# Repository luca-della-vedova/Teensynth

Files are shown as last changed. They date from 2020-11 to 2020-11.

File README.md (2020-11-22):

# Teensynth

The aim of the project is to create a companion board for MIDI compatible keyboards / electric pianos and augment them with commonly used / needed features such as:

* Midi recording: Sample and forward USB Midi signal and forward it to the host machine (or record in an SD card).
* Audio recording: Record Line out / Headphone out (for now only the latter is implemented) and stream it to the host through an Audio USB device interface.
* Midi synthesizer: Read MIDI files from SD card or receive MIDI commands from USB interface and synthesize them, as well as mix them with the audio signal (i.e. create a midi base and jam on it!)
* Implement pitch bend: For keyboards that support pitch bend MIDI commands but don't have a pitch wheel, create one with a joystick / potentiometer.

The board aims to be used in two ways:

### Standalone mode

All the recording outputs are to SD card, all the inputs (i.e. MIDI) are from SD card or firmware, control is done through hardware buttons and feedback to the user is through the Grove compatible I2C LCD display. 

### USB device mode

The device implements bidirectional MIDI (send the keyboard output to the host machine / synthesize the host machine's output) and Audio streaming to the host machine.
Streaming audio from the host machine to the onboard DAC should also be possible but is not a priority right now.

# Hardware

The hardware has been designed with kicad, it is a carrier board for  Teensy 4.1 and the Adafruit VS1053B breakout board.

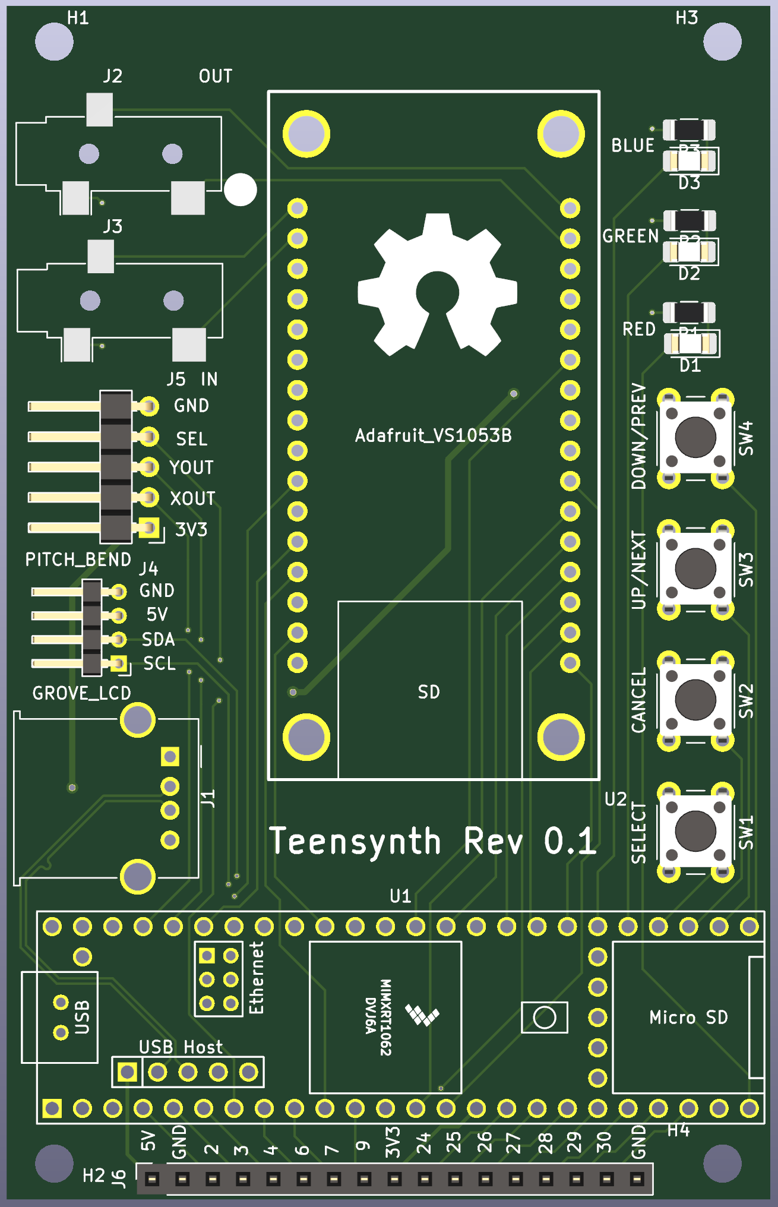
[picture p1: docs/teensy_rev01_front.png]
teensy_rev01_front


# Firmware

The firmware has been developed with the Arduino / Teensyduino IDE, using external libraries (such as Adafruit VS1053B library) when necessary.

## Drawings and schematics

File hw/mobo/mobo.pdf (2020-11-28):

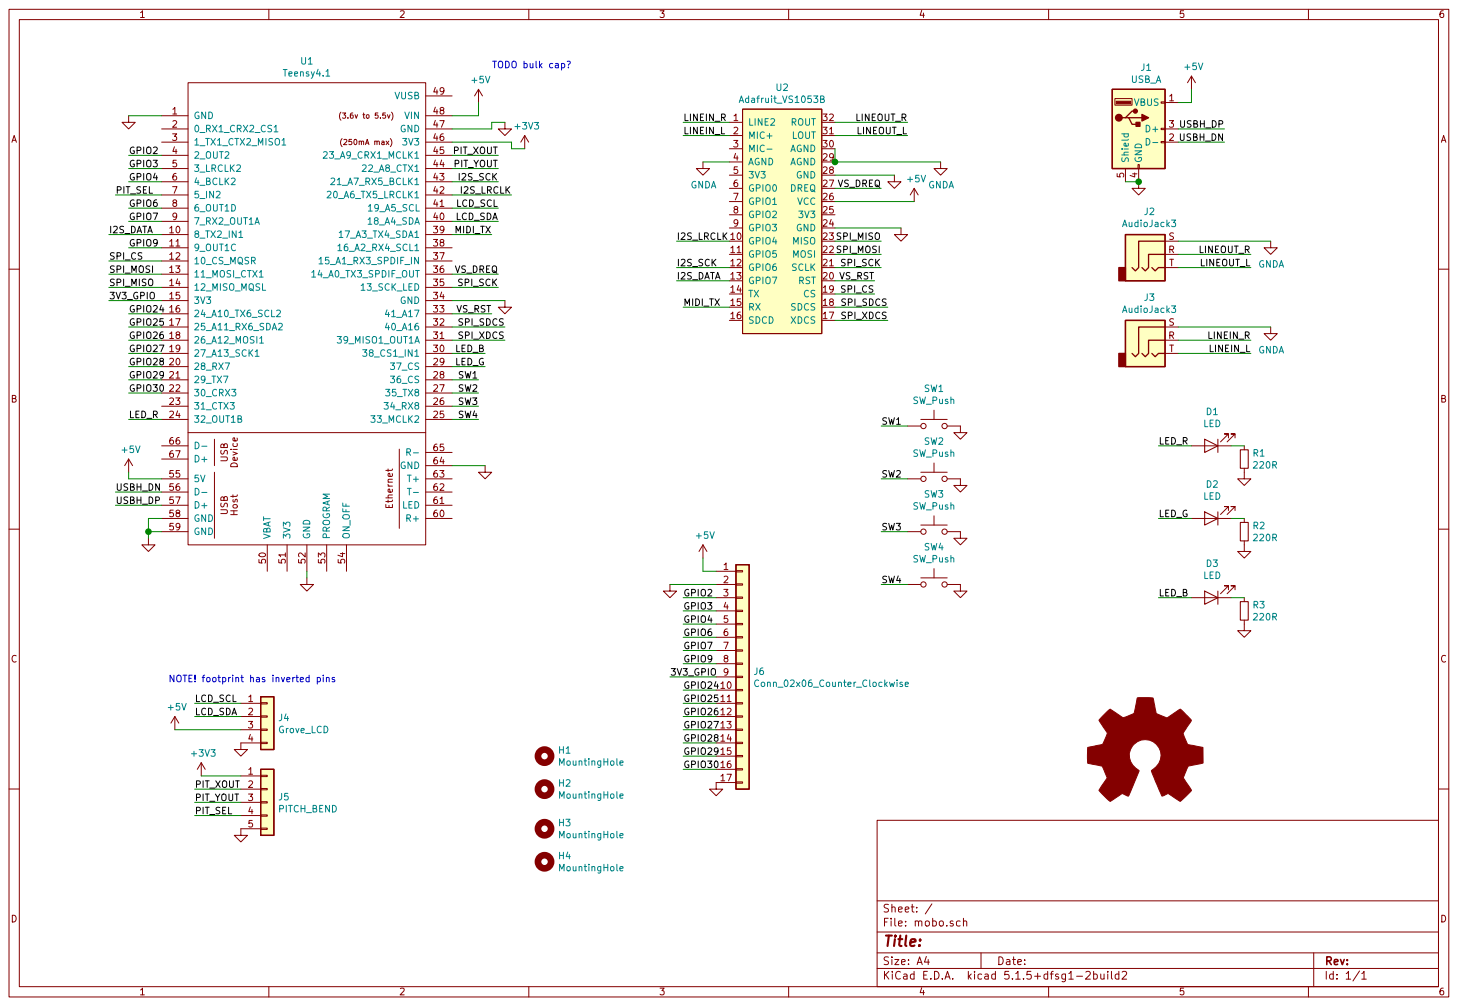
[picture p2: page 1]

NOTE! footprint has inverted pins
LCD_SDA

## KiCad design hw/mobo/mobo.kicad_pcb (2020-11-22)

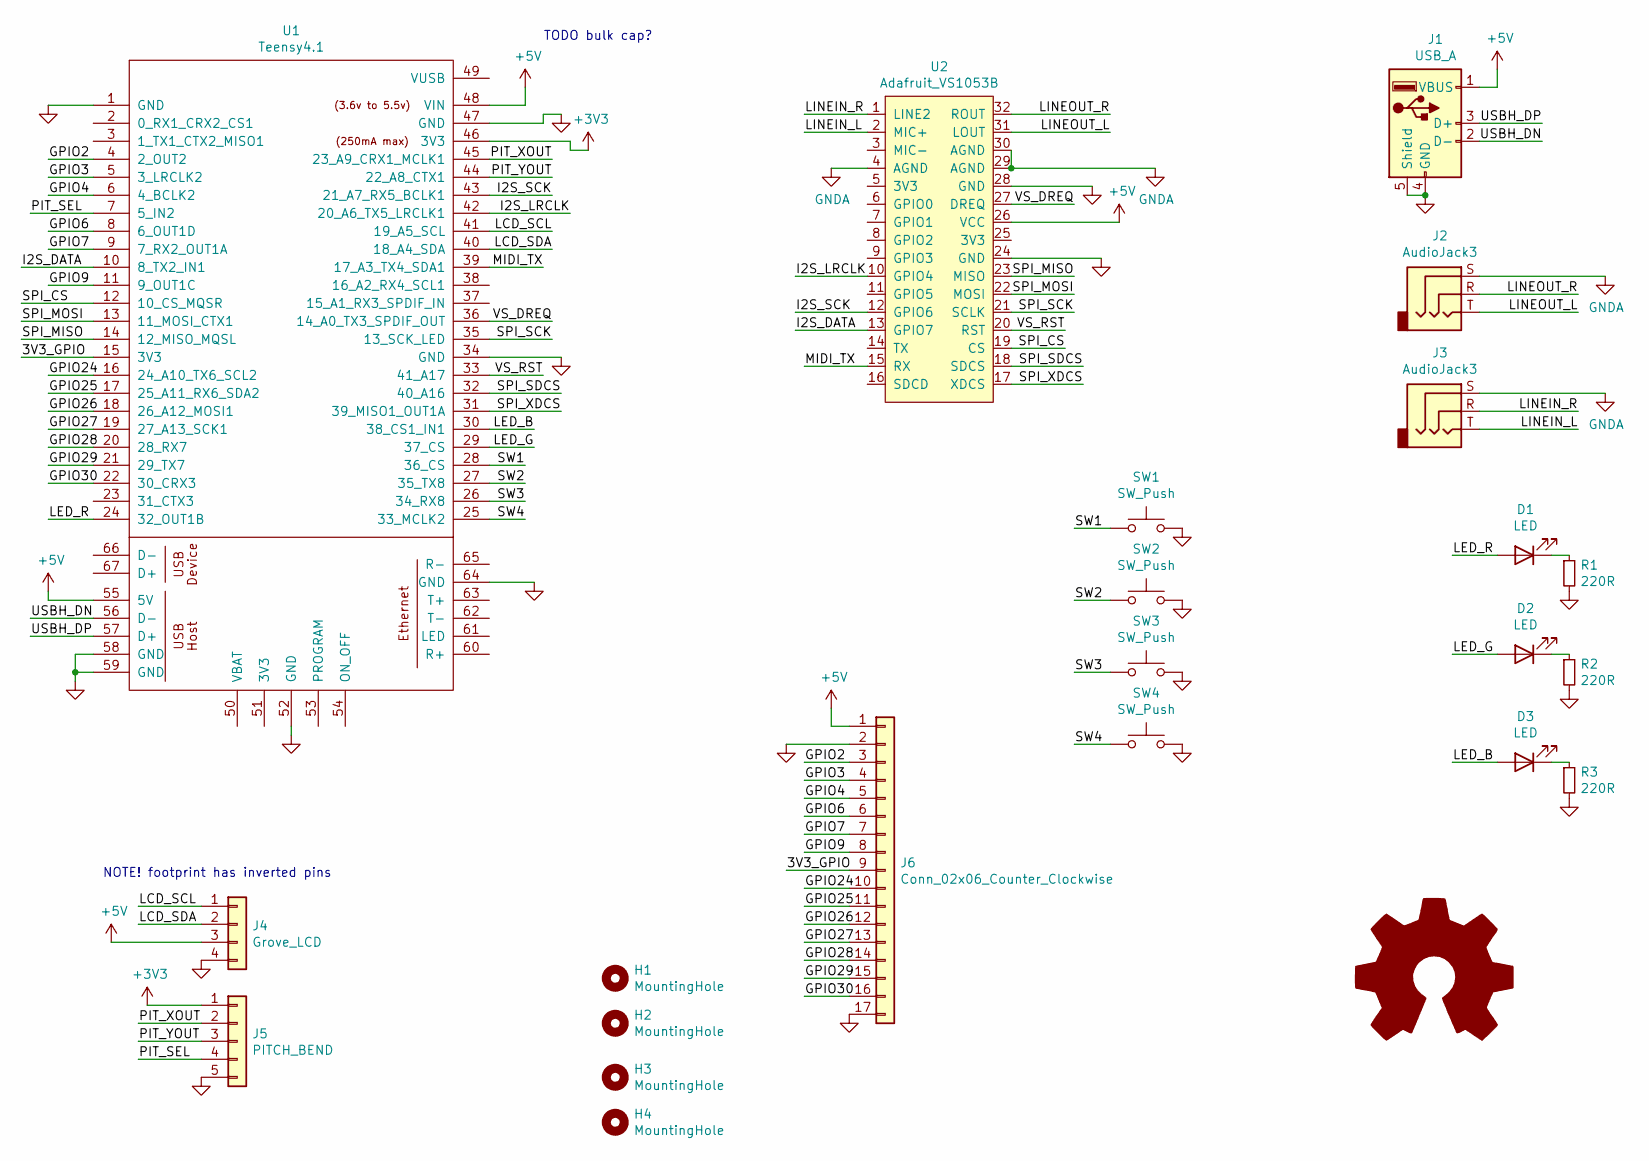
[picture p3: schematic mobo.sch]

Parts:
D1, D2, D3: LED; LED_1206_3216Metric_Pad1.42x1.75mm_HandSolder
H1, H2, H3, H4: MountingHole; MountingHole_3.2mm_M3
J1: USB_A; USB_A_Molex_67643_Horizontal
J2, J3: AudioJack3; Jack_3.5mm_CUI_SJ-3523-SMT_Horizontal
J4: Grove_LCD; PinHeader_1x04_P2.00mm_Horizontal
J5: PITCH_BEND; PinHeader_1x05_P2.54mm_Horizontal
J6: Conn_02x06_Counter_Clockwise; PinSocket_1x17_P2.54mm_Vertical
LOGO1: Logo_Open_Hardware_Large; OSHW-Symbol_13.4x12mm_SilkScreen
R1, R2, R3: 220R; R_1206_3216Metric_Pad1.30x1.75mm_HandSolder
SW1, SW2, SW3, SW4: SW_Push; SW_PUSH_6mm_H5mm
U1: Teensy4.1; Teensy41
U2: Adafruit_VS1053B

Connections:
+3V3: J5.1, U1.46 (3V3)
+5V: J1.1 (VBUS), J4.3, J6.1, U1.48 (VIN), U1.55 (5V), U2.26 (VCC)
/3V3_GPIO: J6.9, U1.15 (3V3)
/GPIO2: J6.3, U1.4 (2_OUT2)
/GPIO3: J6.4, U1.5 (3_LRCLK2)
/GPIO4: J6.5, U1.6 (4_BCLK2)
/GPIO6: J6.6, U1.8 (6_OUT1D)
/GPIO7: J6.7, U1.9 (7_RX2_OUT1A)
/GPIO9: J6.8, U1.11 (9_OUT1C)
/GPIO24: J6.10, U1.16 (24_A10_TX6_SCL2)
/GPIO25: J6.11, U1.17 (25_A11_RX6_SDA2)
/GPIO26: J6.12, U1.18 (26_A12_MOSI1)
/GPIO27: J6.13, U1.19 (27_A13_SCK1)
/GPIO28: J6.14, U1.20 (28_RX7)
/GPIO29: J6.15, U1.21 (29_TX7)
/GPIO30: J6.16, U1.22 (30_CRX3)
/I2S_DATA: U1.10 (8_TX2_IN1), U2.13 (GPIO7)
/I2S_LRCLK: U1.42 (20_A6_TX5_LRCLK1), U2.10 (GPIO4)
/I2S_SCK: U1.43 (21_A7_RX5_BCLK1), U2.12 (GPIO6)
/LCD_SCL: J4.1, U1.41 (19_A5_SCL)
/LCD_SDA: J4.2, U1.40 (18_A4_SDA)
/LED_B: D3.2 (A), U1.30 (38_CS1_IN1)
/LED_G: D2.2 (A), U1.29 (37_CS)
/LED_R: D1.2 (A), U1.24 (32_OUT1B)
/LINEIN_L: J3.T, U2.2 (MIC+)
/LINEIN_R: J3.R, U2.1 (LINE2)
/LINEOUT_L: J2.T, U2.31 (LOUT)
/LINEOUT_R: J2.R, U2.32 (ROUT)
/MIDI_TX: U1.39 (17_A3_TX4_SDA1), U2.15 (RX)
/PIT_SEL: J5.4, U1.7 (5_IN2)
/PIT_XOUT: J5.2, U1.45 (23_A9_CRX1_MCLK1)
/PIT_YOUT: J5.3, U1.44 (22_A8_CTX1)
/SPI_CS: U1.12 (10_CS_MQSR), U2.19 (CS)
/SPI_MISO: U1.14 (12_MISO_MQSL), U2.23 (MISO)
/SPI_MOSI: U1.13 (11_MOSI_CTX1), U2.22 (MOSI)
/SPI_SCK: U1.35 (13_SCK_LED), U2.21 (SCLK)
/SPI_SDCS: U1.32 (40_A16), U2.18 (SDCS)
/SPI_XDCS: U1.31 (39_MISO1_OUT1A), U2.17 (XDCS)
/SW1: SW1.1, U1.28 (36_CS)
/SW2: SW2.1, U1.27 (35_TX8)
/SW3: SW3.1, U1.26 (34_RX8)
/SW4: SW4.1, U1.25 (33_MCLK2)
/USBH_DN: J1.2 (D-), U1.56 (D-)
/USBH_DP: J1.3 (D+), U1.57 (D+)
/VS_DREQ: U1.36 (14_A0_TX3_SPDIF_OUT), U2.27 (DREQ)
/VS_RST: U1.33 (41_A17), U2.20 (RST)
GND: J1.4 (GND), J1.5 (Shield), J4.4, J5.5, J6.2, J6.17, R1.2, R2.2, R3.2, SW1.2, SW2.2, SW3.2, SW4.2, U1.1 (GND), U1.34 (GND), U1.47 (GND), U1.52 (GND), U1.58 (GND), U1.59 (GND), U1.64 (GND), U2.24 (GND), U2.28 (GND)
GNDA: J2.S, J3.S, U2.4 (AGND), U2.29 (AGND), U2.30 (AGND)
unnamed: D1.1 (K), R1.1
unnamed: D2.1 (K), R2.1
unnamed: D3.1 (K), R3.1

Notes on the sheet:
TODO bulk cap?
NOTE! footprint has inverted pins

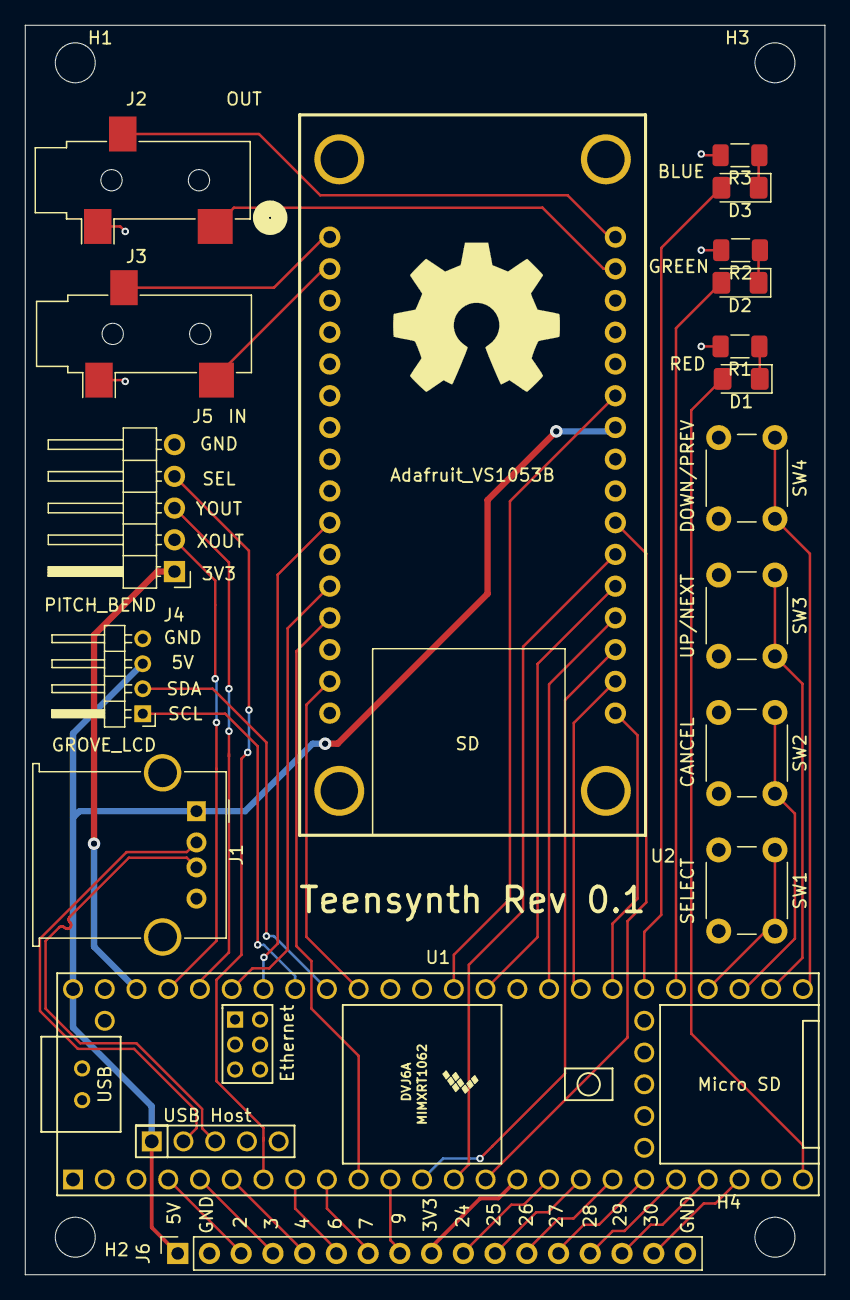
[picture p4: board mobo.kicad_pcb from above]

Board: 2 copper layers, 64.0 x 100.0 mm, 23 parts (0 on the bottom side), 51 nets.

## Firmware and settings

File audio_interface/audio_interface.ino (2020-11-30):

#define PREFER_SDFAT_LIBRARY
#define FILES_PER_PAGE 10
#include <array>

#include <SdFat.h>

#include <USBHost_t36.h>
#include <Metro.h>
#include <Adafruit_VS1053.h>
#include "hw_defs.h"
#include "vs1053_plugins.h"
#include "lcd_driver.h"

#include <MD_MIDIHelper.h>
#include <MD_MIDIFile.h>

USBHost myusb;
USBHub hub1(myusb);
USBHub hub2(myusb);
MIDIDevice midi1(myusb);

Adafruit_VS1053 vs_codec =
  Adafruit_VS1053(VS1053_RESET, VS1053_CS, VS1053_DCS, VS1053_DREQ);


#define VS1053_BANK_MELODY 0x79
#define VS1053_GM1_OCARINA 80

#define MIDI_NOTE_ON  0x90
#define MIDI_NOTE_OFF 0x80
#define MIDI_CHAN_MSG 0xB0
#define MIDI_CHAN_BANK 0x00
#define MIDI_CHAN_VOLUME 0x07
#define MIDI_CHAN_PROGRAM 0xC0

void midiSetInstrument(uint8_t chan, uint8_t inst) {
  if (chan > 15) return;
  inst --; // page 32 has instruments starting with 1 not 0 :(
  if (inst > 127) return;
  
  VS1053_MIDI.write(MIDI_CHAN_PROGRAM | chan);  
  VS1053_MIDI.write(inst);
}

void midiSetChannelVolume(uint8_t chan, uint8_t vol) {
  if (chan > 15) return;
  if (vol > 127) return;
  
  VS1053_MIDI.write(MIDI_CHAN_MSG | chan);
  VS1053_MIDI.write(MIDI_CHAN_VOLUME);
  VS1053_MIDI.write(vol);
}

void midiSetChannelBank(uint8_t chan, uint8_t bank) {
  if (chan > 15) return;
  if (bank > 127) return;
  
  VS1053_MIDI.write(MIDI_CHAN_MSG | chan);
  VS1053_MIDI.write((uint8_t)MIDI_CHAN_BANK);
  VS1053_MIDI.write(bank);
}

SdFat  SD;
MD_MIDIFile SMF;

// The files in the tune list should be located on the SD card 
// or an error will occur opening the file and the next in the 
// list will be opened (skips errors).
const char *tuneList[] = 
{
  "sandstorm.mid",  // simplest and shortest file
  "pirates.mid",
};
const uint16_t WAIT_DELAY = 2000; // ms

void midiCallback(midi_event *pev)
// Called by the MIDIFile library when a file event needs to be processed
// thru the midi communications interface.
// This callback is set up in the setup() function.
{
  if ((pev->data[0] >= 0x80) && (pev->data[0] <= 0xe0))
  {
    VS1053_MIDI.write(pev->data[0] | pev->channel);
    VS1053_MIDI.write(&pev->data[1], pev->size-1);
  }
  else
    VS1053_MIDI.write(pev->data, pev->size);
}

void midiSilence(void)
// Turn everything off on every channel.
// Some midi files are badly behaved and leave notes hanging, so between songs turn
// off all the notes and sound
{
  midi_event ev;

  // All sound off
  // When All Sound Off is received all oscillators will turn off, and their volume
  // envelopes are set to zero as soon as possible.
  ev.size = 0;
  ev.data[ev.size++] = 0xb0;
  ev.data[ev.size++] = 120;
  ev.data[ev.size++] = 0;

  for (ev.channel = 0; ev.channel < 16; ev.channel++)
    midiCallback(&ev);
}

void midifile_setup(void)
{
  // Set up LED pins
  pinMode(READY_LED, OUTPUT);
  pinMode(SD_ERROR_LED, OUTPUT);
  pinMode(SMF_ERROR_LED, OUTPUT);
  pinMode(BEAT_LED, OUTPUT);

  // reset LEDs
  digitalWrite(READY_LED, LOW);
  digitalWrite(SD_ERROR_LED, LOW);
  digitalWrite(SMF_ERROR_LED, LOW);
  digitalWrite(BEAT_LED, LOW);

  SdioConfig sd_config;
  // Initialize SD
  if (!SD.begin(sd_config))
  {
    digitalWrite(SD_ERROR_LED, HIGH);
    while (true)
      Serial.println("SD init failed");
  }

  // Initialize MIDIFile
  SMF.begin(&SD);
  SMF.setMidiHandler(midiCallback);
  
  digitalWrite(READY_LED, HIGH);
}

void tickMetronome(void)
// flash a LED to the beat
{
  static uint32_t lastBeatTime = 0;
  static boolean  inBeat = false;
  uint16_t  beatTime;

  beatTime = 60000/SMF.getTempo();    // msec/beat = ((60sec/min)*(1000 ms/sec))/(beats/min)
  if (!inBeat)
  {
    if ((millis() - lastBeatTime) >= beatTime)
    {
      lastBeatTime = millis();
      digitalWrite(BEAT_LED, HIGH);
      inBeat = true;
    }
  }
  else
  {
    if ((millis() - lastBeatTime) >= 100) // keep the flash on for 100ms only
    {
      digitalWrite(BEAT_LED, LOW);
      inBeat = false;
    }
  }
}

void midifile_loop(void)
{
  static enum { S_IDLE, S_PLAYING, S_END, S_WAIT_BETWEEN } state = S_IDLE;
  static uint16_t currTune = ARRAY_SIZE(tuneList);
  static uint32_t timeStart;

  switch (state)
  {
  case S_IDLE:    // now idle, set up the next tune
    {
      int err;

      digitalWrite(READY_LED, LOW);
      digitalWrite(SMF_ERROR_LED, LOW);

      currTune++;
      if (currTune >= ARRAY_SIZE(tuneList))
        currTune = 0;

      // use the next file name and play it
      err = SMF.load(tuneList[currTune]);
      if (err != MD_MIDIFile::E_OK)
      {
        digitalWrite(SMF_ERROR_LED, HIGH);
        timeStart = millis();
        state = S_WAIT_BETWEEN;
      }
      else
      {
        state = S_PLAYING;
      }
    }
    break;

  case S_PLAYING: // play the file
    if (!SMF.isEOF())
    {
      if (SMF.getNextEvent())
        tickMetronome();
    }
    else
      state = S_END;
    break;

  case S_END:   // done with this one
    SMF.close();
    midiSilence();
    timeStart = millis();
    state = S_WAIT_BETWEEN;
    break;

  case S_WAIT_BETWEEN:    // signal finished with a dignified pause
    digitalWrite(READY_LED, HIGH);
    if (millis() - timeStart >= WAIT_DELAY)
      state = S_IDLE;
    break;

  default:
    state = S_IDLE;
    break;
  }
}

void VS1053_init()
{
  delay(100);
  if (! vs_codec.begin()) { // initialise the music player
      Serial.println(F("Couldn't find VS1053, do you have the right pins defined?"));
  }
  Serial.println("VS1053 found");
  // Magic stuff to enable I2S based on datasheet
  vs_codec.sciWrite(0x7, 0xC017);
  vs_codec.sciWrite(0x6, 0x00F0);

  // Enable I2S, start with WRAMADDR
  vs_codec.sciWrite(0x7, 0xC040);
  // Then WRAM
  vs_codec.sciWrite(0x6, 0x000E); // PUT E FOR 192KHZ
  vs_codec.applyPatch(patches_plugin, PATCHES_PLUGIN_SIZE);// Add here
  // Start the patches
  while(digitalRead(VS1053_DREQ) == 0);
  vs_codec.applyPatch(midistart_plugin, MIDISTART_PLUGIN_SIZE);// Add here
//  // Start midi plugin
//  vs_codec.sciWrite(0xA, 0x50);
  delay(50);
  
  vs_codec.applyPatch(admix_plugin, ADMIX_PLUGIN_SIZE);// Add here

  // Start the ADMIX plugin
  // Lower gain
  vs_codec.sciWrite(0xC, 0xFFFD);
  vs_codec.sciWrite(0xA, 0x0F00);
  while(digitalRead(VS1053_DREQ) == 0)
  {
    Serial.println("Waiting for ADMIX start");
  }
  delay(100);
  
  VS1053_MIDI.begin(31250); // MIDI uses a 'strange baud rate'
  midiSetChannelBank(0, VS1053_BANK_MELODY);
  midiSetInstrument(0, VS1053_GM1_OCARINA);
  midiSetChannelVolume(0, 127);
}

void midiNoteOn(uint8_t chan, uint8_t n, uint8_t vel) {
  if (chan > 15) return;
  if (n > 127) return;
  if (vel > 127) return;
  
  VS1053_MIDI.write(MIDI_NOTE_ON | chan);
  VS1053_MIDI.write(n);
  VS1053_MIDI.write(vel);
}

void midiNoteOff(uint8_t chan, uint8_t n, uint8_t vel) {
  if (chan > 15) return;
  if (n > 127) return;
  if (vel > 127) return;
  
  VS1053_MIDI.write(MIDI_NOTE_OFF | chan);
  VS1053_MIDI.write(n);
  VS1053_MIDI.write(vel);
}

AudioLCD lcd;

std::array<String, FILES_PER_PAGE> probe_sd_files()
{
  std::array<String, FILES_PER_PAGE> ret_arr;
  int file_count = 0;
  char name_buf[50];
  File file;
  File dir;
  // Open root directory
  dir.open("/");
  while (file.openNext(&dir, O_READ) && file_count < FILES_PER_PAGE)
  {
    file.getName(name_buf, sizeof(name_buf));
    size_t name_size = strlen(name_buf);
    if (name_size == sizeof(name_buf))
      Serial.println("WARNING: buffer overflow in name size");
    if (file.isDir())
    {
      Serial.println("WARNING: Found a folder, skipping");
    }
    else
    {
      // Check extension
      if (strstr(strlwr(name_buf + (name_size - 4)), ".mid"))
      {
        Serial.print("Found midi file: ");
        Serial.println(name_buf);
        ret_arr[file_count] = String(name_buf);
        ++file_count;
      }
    }
    file.close();
  }
  return ret_arr;
}

void setup() {
  Serial.begin(115200);
  midifile_setup();
  int tmp = 0;
  lcd.printMenu(tmp);
  delay(2000);
  pinMode(VS1053_DREQ, INPUT);
  // Initialize VS1053 chip
  VS1053_init();

  // Wait 1.5 seconds before turning on USB Host.  If connected USB devices
  // use too much power, Teensy at least completes USB enumeration, which
  // makes isolating the power issue easier.
  delay(1000);
  Serial.println("USB Host InputFunctions example");
  delay(10);
  myusb.begin();

  // Find all the files in the SD card
//  lcd.setS  dFiles(probe_sd_files());

  midi1.setHandleNoteOn(myNoteOn);
  midi1.setHandleNoteOff(myNoteOff);
  midi1.setHandleControlChange(myControlChange);
  midi1.setHandleProgramChange(myProgramChange);
}

void test_midi_send()
{
  static constexpr int NOTE_DT = 500;
  static uint32_t last_t = 0;
  static bool note_status = 0;
  uint32_t current_t = millis();
  if (current_t - last_t > NOTE_DT)
  {
    if (note_status == 0)
    {
      // Turn on
      midiNoteOn(0, 60, 127);
//      midi1.sendNoteOn(60, 99, 0); // TODO check channel
    }
    else
    {
      // Turn off
      midiNoteOff(0, 60, 127);
//      midi1.sendNoteOff(60, 99, 0);
    }
    note_status = !note_status;
    last_t = current_t;
  }
//  midi1.sendPitchBend((current_t - last_t) * 10, 0);
}

// 20 Hz sampling
Metro pitch_bend_sampler = Metro(50);

void samplePitchBend()
{
  // Basic calibration, get the first reading as a reference
  static int init_bend_val = analogRead(0);
  static int last_bend_val = init_bend_val;
  int bend_val = analogRead(0); // Pin 14 on the board
  // Rescale from 0 to 16384
  // Only send if there has been a change
  if (bend_val != last_bend_val)
  {
    bend_val <<= 4;
    // And subtract the mid
    bend_val -= 8192;
    midi1.sendPitchBend(bend_val, 1);
    last_bend_val = bend_val;
  }
  test_midi_send();
}

void loop() {
  // The handler functions are called when midi1 reads data.  They
  // will not be called automatically.  You must call midi1.read()
  // regularly from loop() for midi1 to actually read incoming
  // data and run the handler functions as messages arrive.
  myusb.Task();
  midi1.read();
  midifile_loop();
  lcd.update();
  // Check if it's time to send the pitch bend value
//  if (pitch_bend_sampler.check())
//    samplePitchBend();
}


void myNoteOn(byte channel, byte note, byte velocity) {
  // When a USB device with multiple virtual cables is used,
  // midi1.getCable() can be used to read which of the virtual
  // MIDI cables received this message.
  usbMIDI.sendNoteOn(channel, note, velocity);
}

void myNoteOff(byte channel, byte note, byte velocity) {
  usbMIDI.sendNoteOff(channel, note, velocity);
}

void myControlChange(byte channel, byte control, byte value) {
  usbMIDI.sendControlChange(channel, control, value);
}

void myProgramChange(byte channel, byte program) {
  usbMIDI.sendProgramChange(channel, program);
}

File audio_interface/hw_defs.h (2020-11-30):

// Defines for VS1053B board
#define VS1053_RESET  41      // VS1053 reset pin (output)
#define VS1053_CS     10     // VS1053 chip select pin (output)
#define VS1053_DCS    93      // VS1053 Data/command select pin (output)

#define VS1053_CARDCS 40     // Card chip select pin
#define VS1053_DREQ 14       // VS1053 Data request, ideally an Interrupt pin

#define VS1053_MIDI Serial4

// LEDS
#define LED_R 32
#define LED_G 37
#define LED_B 38

#define BEAT_LED LED_B
#define READY_LED LED_G
#define SD_ERROR_LED LED_R
#define SMF_ERROR_LED LED_R

// Buttons
#define SW_SELECT 36
#define SW_CANCEL 35
#define SW_NEXT 34
#define SW_PREV 33

// Pitch bend pot
#define POT_X 9
#define POT_Y 8

// Grove LCD I2C, just default I2C
#define LCD_I2C Wire

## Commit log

2020-11-15 First commit, pitch bend and VS1052 basic implem
2020-11-22 Add kicad libraries for board
2020-11-22 Rev 0.1 sent for fab
    [mobo-B_Cu.gbr, mobo-B_Mask.gbr, mobo-B_Paste.gbr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]
2020-11-22 Some docs / board rendering
2020-11-28 Add schematic printout
